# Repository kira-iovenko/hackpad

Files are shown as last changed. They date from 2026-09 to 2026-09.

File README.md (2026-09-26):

# Kira Hackpad

A 12-key custom macropad with a rotary encoder and a little OLED screen, built from scratch - PCB, case, and firmware.

## Features

- 12 keys in a 4x3 grid
- Rotary encoder for volume
- 0.91" OLED display for status
- Runs on a Seeed XIAO RP2040
- QMK firmware

## Hardware

- Controller: Seeed XIAO RP2040
- Switches: 12x Cherry MX
- Diodes: 12x 1N4148
- Encoder: EC11 rotary encoder
- Display: 0.91" SSD1306 OLED (128x32)

## PCB

Designed in KiCad. It's a simple 2-layer board - a 2x4 switch matrix with per-key diodes, XIOA footprint, encoder, and OLED. Source files are in ['pcb/'](pcb/) (schematic, layout, and STEP export).

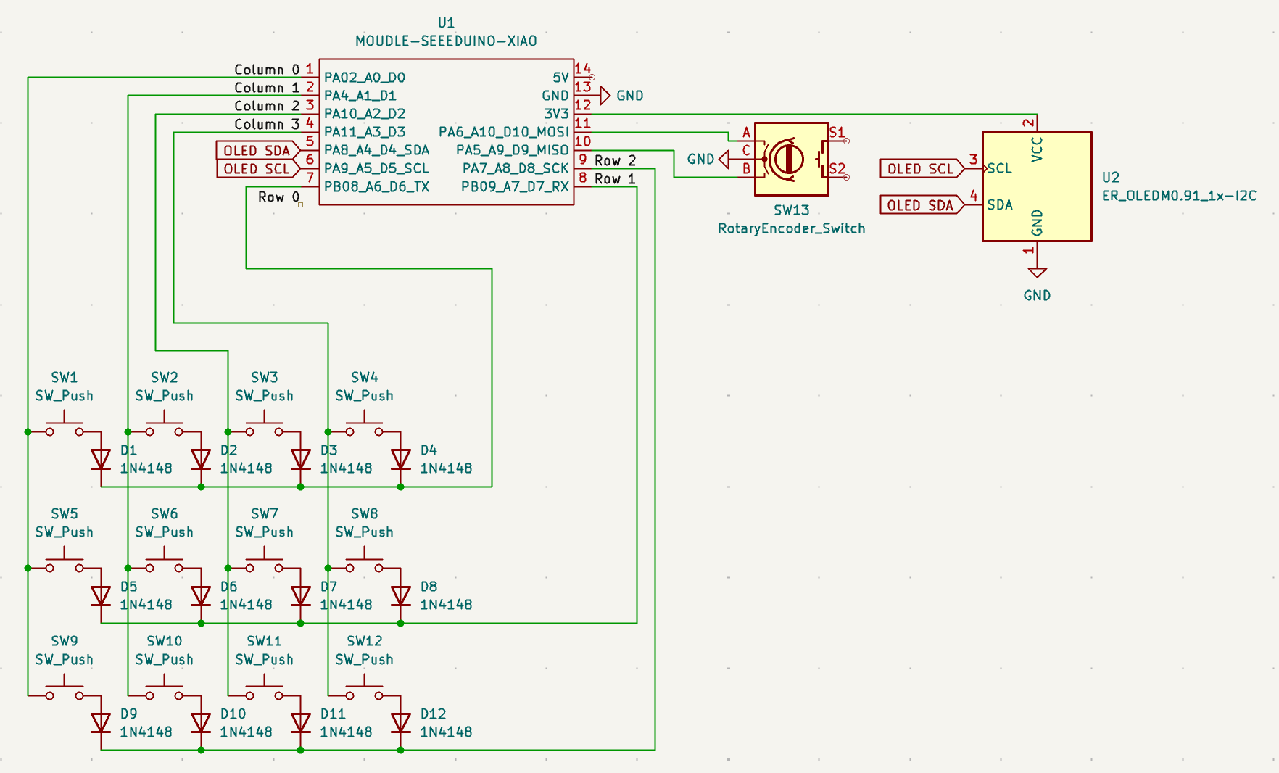
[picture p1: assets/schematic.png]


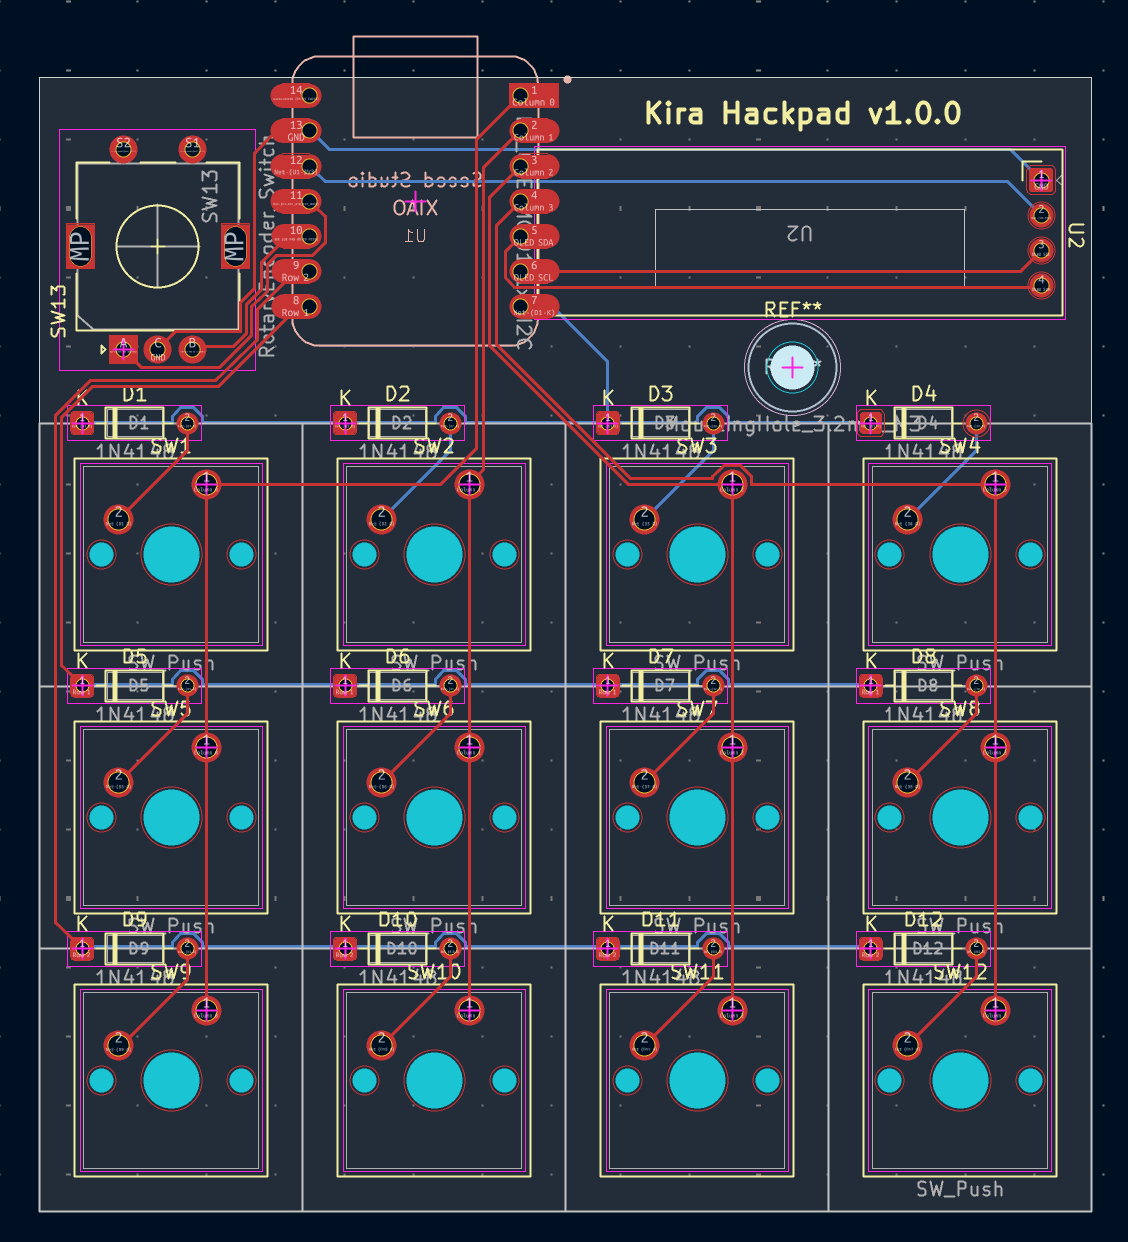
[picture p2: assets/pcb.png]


## Case

Designed in Fusion 360, in three printed parts: the angle, the base where the PCB sits, and the top cover. They fits together using 5 M3 bolts and heatset inserts - 4 cor the case and one for the PCB. The design is in ['cad/'](cad/).

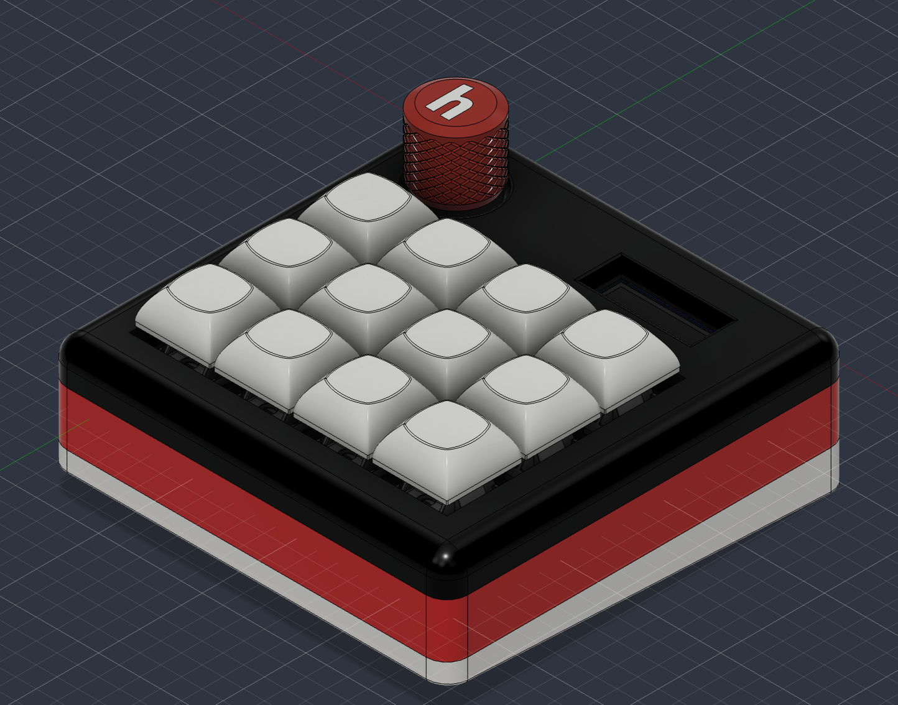
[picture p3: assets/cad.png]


## Firmware

Written with QMK and lives in ['firmware/'](firmware/). The keys are laid out for editing + media shortcuts, the encoder controls volume, and OLED shows a status readout. A ready-to-flash `firmware.uf2` is in ['production/'](production/).

### Keymap

| | | |
|-|-|-|
| Undo | Redo  | Cut  | Prev |
| Copy | Paste | Save | Play |
| All  | Find  | Mute | Next |

Encoder: turn = Volume Down / Up

"Undo", "Redo", "Cut", "Prev", "Copy", "Paste", "Save", "Play", "Select All", and "Find" are sent as **Ctrl+key**, which works on Windows. On macOS remap them to `G(...)` (Cmd) in `keymaps/default/keymap.c`.

### Flash

To flash: put the XIAO RP2040 into bootloader mode (double-tap RESET or hold BOOT while plugging in). It appears as a USB drive - copy `firmware.utf2` onto it. The board reboots into the firmware.

### Customizing

- Keys - edit the `LAYOUT(...)` block in `keymaps/default/keymap.c`.
- Encoder - edit the `encoder_map` in the same file.
- OLED text - edit `oled_task_user()` in the same file.

## Built with

- KiCad (PCB)
- Fusion 360 (case)
- QMK (firmware)

## Bill of Materials

### Components

| Qty | Component | Notes |
| --: | --- | --- |
| 1 | Seeed Studio XIAO RP2040 | Main microcontroller |
| 1 | 0.91" SSD1306 OLED Display | 128×32, I2C |
|  12 | MX-style Mechanical Switches | Switches of choice |
|  12 | Blank DSA Keycaps | White |
| 4 | M3×16mm Screws | Enclosure fasteners |
| 1 | M3×12mm Screw | Enclosure fastener |
| 5 | M3×5×4mm Heatset Inserts | Brass threaded inserts |
|  12 | 1N4148 Diodes | Through-hole matrix diodes |
| 1 | Case | Case (3 printed parts) |

### Hack Club Grants

I used/received the following Hack Club grants during the project:

* **Hackpad Kit!** - Hackpad kit containing parts for the project
* **Printing Legion Grant** - $8 shipping credit for a part under 300g
* **Soldering Iron Grant** - $18 grant toward a soldering iron
* **Hackpad PCB Grant** - $10 JLCPCB credit for the Hackpad PCB

## Inspiration

It was was created using guide from Hack Club's Stardance program as a starting point. It was also inspired by [Orpheuspad](https://github.com/qcoral/orpheuspad) and the wider custom hackpad community. Thanks for sharing your bilds!

## Author

Made with ❤️ by [@kira-iovenko](https://github.com/kira-iovenko)

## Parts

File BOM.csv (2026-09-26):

Item | Required Qty | Component Description | Sourcing / Part Notes
1 | 1 | Seeed Studio XIAO RP2040 | Main Microcontroller Board (Unsoldered)
2 | 1 | 0.91 SSD1306 OLED Display | 128x32 Pixel Screen | I2C Interface
3 | 12 | MX-Style Mechanical Switches | Keyswitches of choice
4 | 12 | Blank DSA Keycaps | White keycaps
5 | 4 | M3x16mm Screws | Enclosure fasteners
6 | 1 | M3x12mm Screws | Enclosure fasteners
7 | 5 | M3x5x4mm Heatset Inserts | Brass threaded chassis inserts
8 | 12 | 1N4148 Diodes | Through-hole matrix diodes
9 | 1 | Case | Case (3 printed parts)

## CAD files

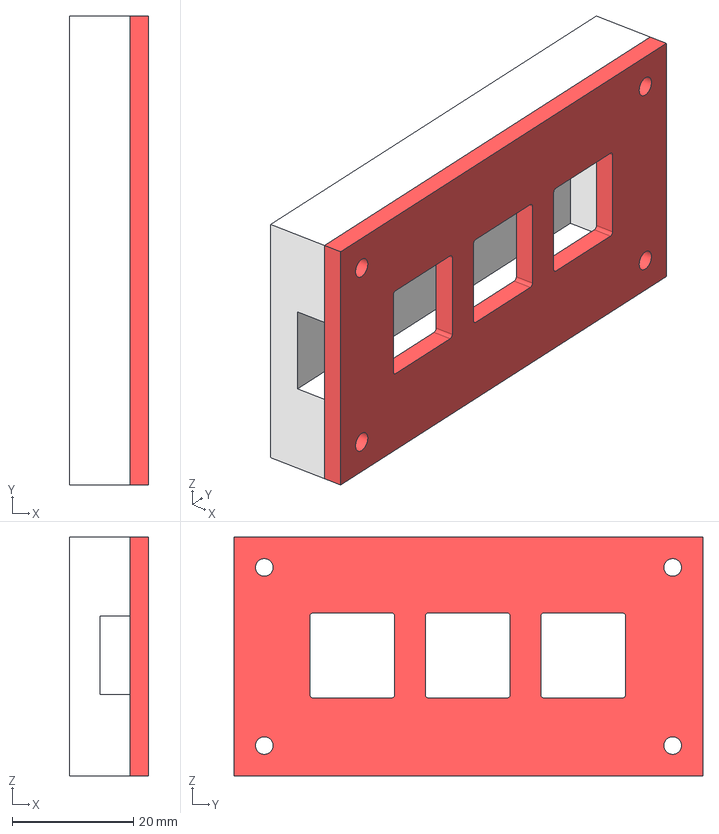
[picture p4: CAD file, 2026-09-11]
cad/hackpad.step
13.0 x 77.4 x 39.4 mm

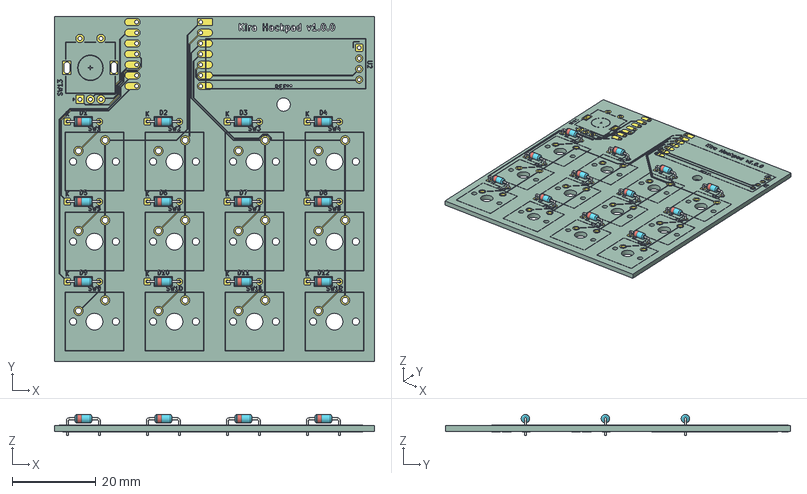
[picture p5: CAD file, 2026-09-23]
pcb/hackpad-pcb.step
76.2 x 82.2 x 5.01 mm
D_DO-35_SOD27_P7.62mm_Horizontal x 12
hackpad_copper
hackpad_silkscreen x 2
hackpad_PCB

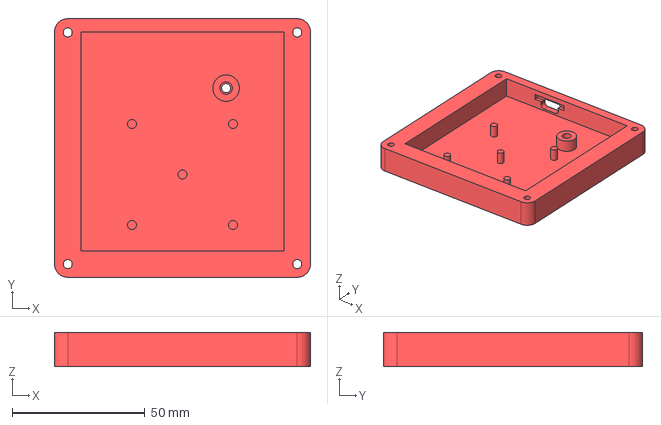
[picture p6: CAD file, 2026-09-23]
production/middle.step
96.6 x 97.6 x 13.0 mm

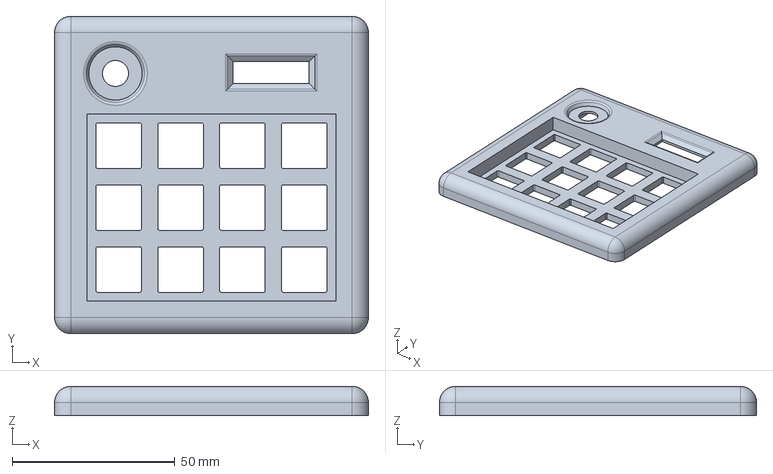
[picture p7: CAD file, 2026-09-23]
production/top.step
96.6 x 97.6 x 9.00 mm

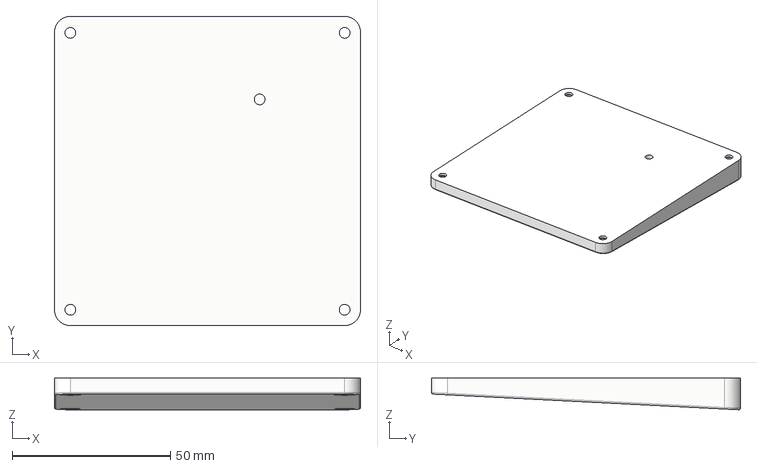
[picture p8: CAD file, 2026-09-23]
production/bottom.step
96.6 x 97.6 x 9.97 mm

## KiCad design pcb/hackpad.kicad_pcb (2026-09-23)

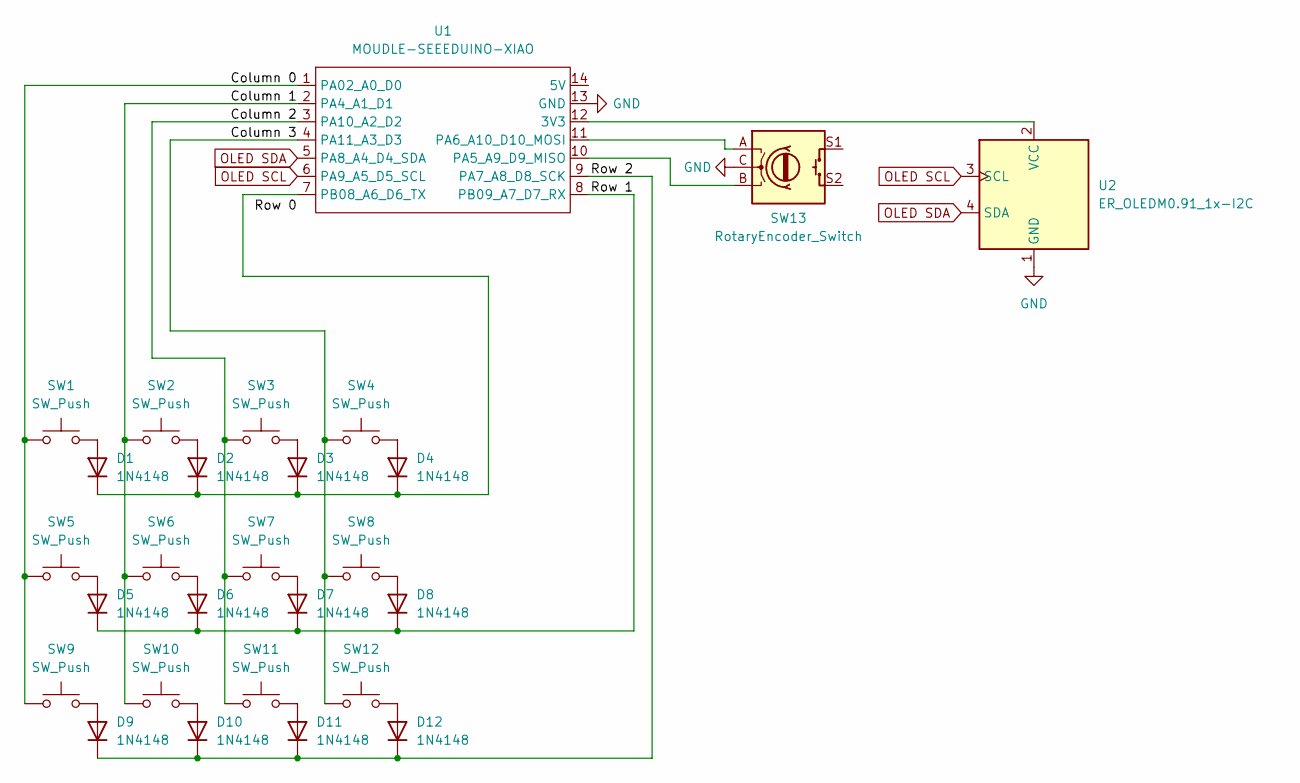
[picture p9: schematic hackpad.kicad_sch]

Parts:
D1, D2, D3, D4, D5, D6, D7, D8, D9, D10, D11, D12: 1N4148; D_DO-35_SOD27_P7.62mm_Horizontal
SW1, SW2, SW3, SW4, SW5, SW6, SW7, SW8, SW9, SW10, SW11, SW12: SW_Push; SW_Cherry_MX_1.00u_PCB
SW13: RotaryEncoder_Switch; RotaryEncoder_Alps_EC11E-Switch_Vertical_H20mm
U1: MOUDLE-SEEEDUINO-XIAO; XIAO-Generic-Hybrid-14P-2.54-21X17.8MM
U2: ER_OLEDM0.91_1x-I2C

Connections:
/Column 0: SW1.1, SW5.1, SW9.1, U1.1 (PA02_A0_D0)
/Column 1: SW2.1, SW6.1, SW10.1, U1.2 (PA4_A1_D1)
/Column 2: SW3.1, SW7.1, SW11.1, U1.3 (PA10_A2_D2)
/Column 3: SW4.1, SW8.1, SW12.1, U1.4 (PA11_A3_D3)
/Row 1: D5.1 (K), D6.1 (K), D7.1 (K), D8.1 (K), U1.8 (PB09_A7_D7_RX)
/Row 2: D9.1 (K), D10.1 (K), D11.1 (K), D12.1 (K), U1.9 (PA7_A8_D8_SCK)
GND: SW13.C, U1.13 (GND), U2.1 (GND)
unnamed: D1.2 (A), SW1.2
unnamed: D1.1 (K), D2.1 (K), D3.1 (K), D4.1 (K), U1.7 (PB08_A6_D6_TX)
unnamed: D2.2 (A), SW2.2
unnamed: D3.2 (A), SW3.2
unnamed: D4.2 (A), SW4.2
unnamed: D5.2 (A), SW5.2
unnamed: D6.2 (A), SW6.2
unnamed: D7.2 (A), SW7.2
unnamed: D8.2 (A), SW8.2
unnamed: D9.2 (A), SW9.2
unnamed: D10.2 (A), SW10.2
unnamed: D11.2 (A), SW11.2
unnamed: D12.2 (A), SW12.2
unnamed: U1.12 (3V3), U2.2 (VCC)
unnamed: SW13.B, U1.10 (PA5_A9_D9_MISO)
unnamed: SW13.A, U1.11 (PA6_A10_D10_MOSI)
OLED SCL: U1.6 (PA9_A5_D5_SCL), U2.3 (SCL)
OLED SDA: U1.5 (PA8_A4_D4_SDA), U2.4 (SDA)

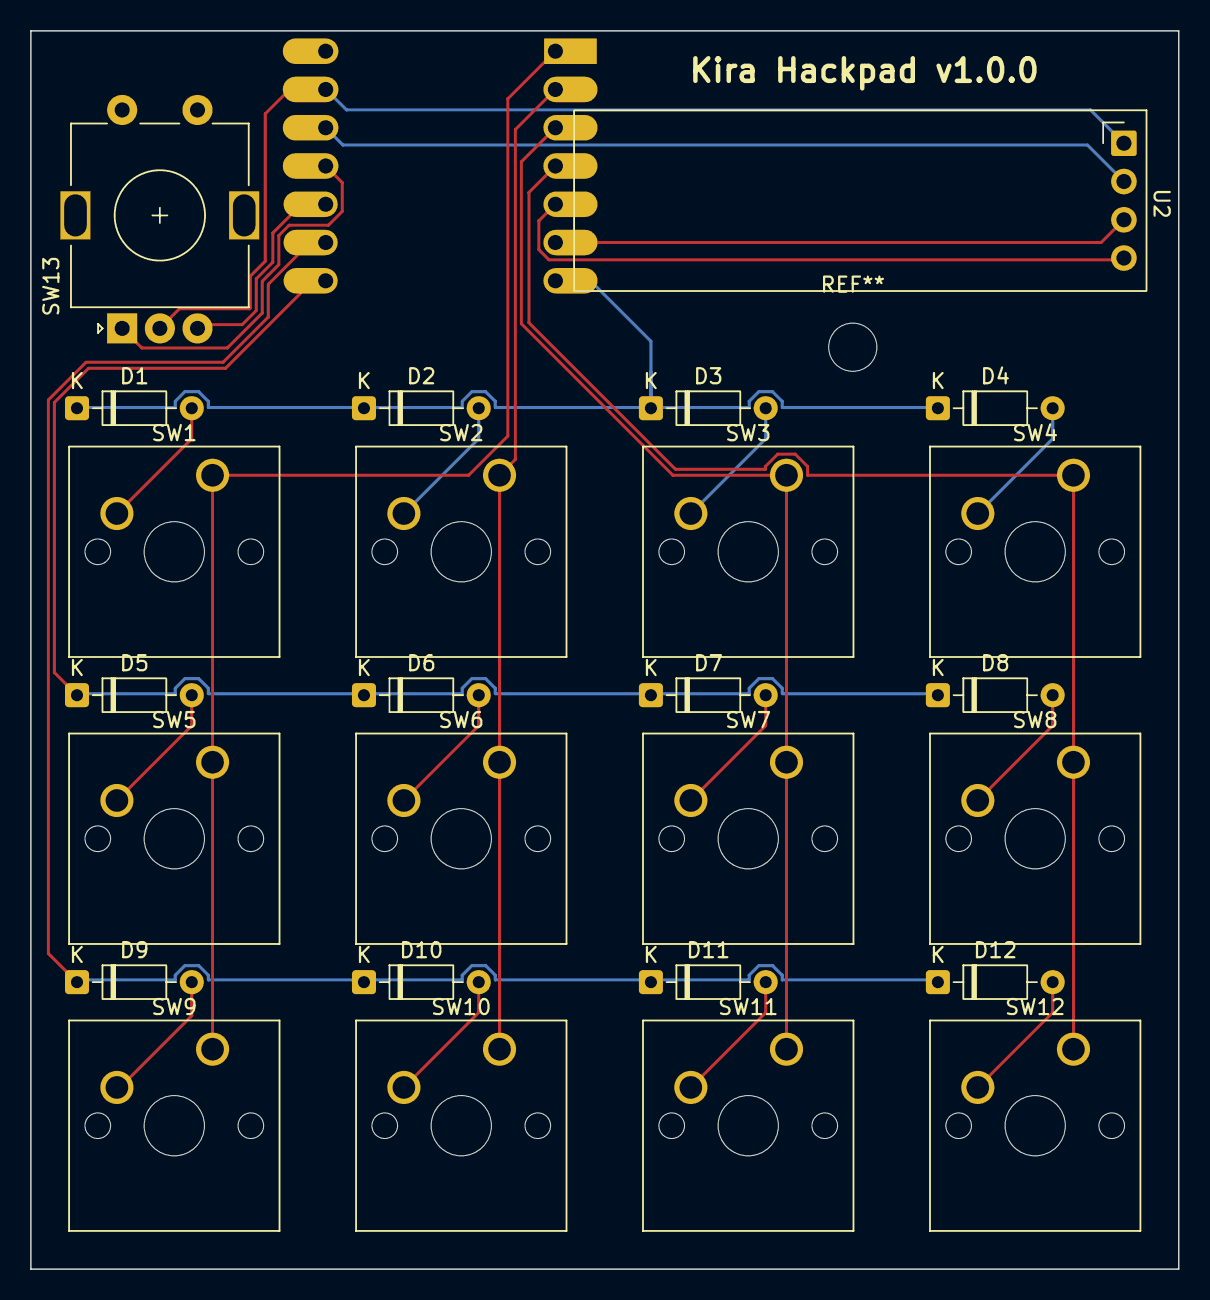
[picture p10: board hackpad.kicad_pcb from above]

Board: 2 copper layers, 76.2 x 82.2 mm, 27 parts (1 on the bottom side), 25 nets.

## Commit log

2026-09-09 Drawing the schematic and route the PCB
    [hackpad.kicad_pcb, hackpad.kicad_sch]
2026-09-11 Design a case in fusion 360
    [hackpad.step]
2026-09-11 Rename PCB folder to lowercase
    [hackpad.kicad_pcb, hackpad.kicad_sch]
2026-09-15 Update the schematic
    [hackpad-pcb.step, hackpad-pcb.stl, hackpad.kicad_pcb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]
2026-09-21 Re-route PCB and update the case
    [hackpad-pcb.step, hackpad-pcb.stl, hackpad.kicad_pcb]
2026-09-22 Update keyboard.json with 3x4 matrix and encoder
2026-09-23 Fix pcb error and reorganize folders
    [hackpad-pcb.step, hackpad-pcb.stl, hackpad.kicad_pcb]
2026-09-23 Rename case parts
2026-09-23 Update the case
    [hackpad.kicad_pcb]
2026-09-23 Export case parts
    [bottom.step, middle.step, top.step]
2026-09-23 Export PCB
2026-09-26 Add BOM
    [BOM.csv]
2026-10-28 Fix BOM format
2026-10-29 Add estimated prices to BOM
